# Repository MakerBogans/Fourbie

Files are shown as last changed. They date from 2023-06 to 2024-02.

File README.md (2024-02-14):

# Fourbie

## Important note
The following information is in regards to the differences between Fourbie v1 and Fourbie v2.
They are both AWD mods for voron 2.4 that use top moutned rails and VZ toolheads. However they are quite different in implementation.
They are labeled v1 and v2 as that is the order they are developed in. v1 is more flexible and compatible if you want to pick and choose which parts of the mod to use, see below. If starting from scratch I strongly recommend you go with v2. v1 is no longer in Active development, however they will continue to be distributed for those who may find them useful in some way.

These are two separate mods, both distributed from this repository in different sub-folders.
Links to the CAD can be found below. Documentation about the specific mods can be found in their specific folders README.MD

CAD can be found here:  https://drive.google.com/drive/u/0/folders/1L2iNjBxE2YqSRG2WW0IpDFqYx307Jbbb

Trident Mods exist in the mods folders

## V2
https://github.com/MakerBogans/Fourbie/tree/main/Fourbie%20v2
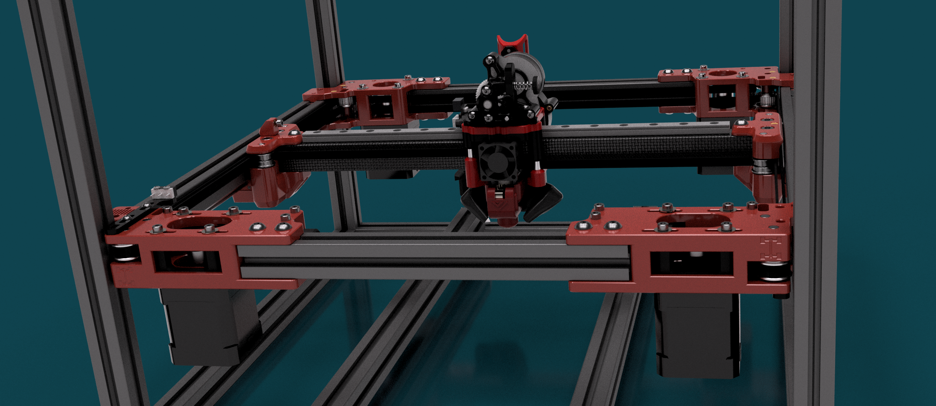
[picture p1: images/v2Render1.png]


## V1
https://github.com/MakerBogans/Fourbie/tree/main/Fourbie%20v1
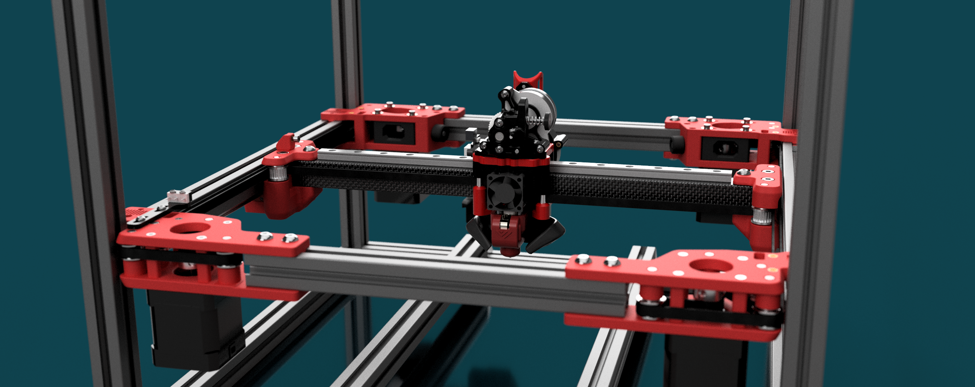
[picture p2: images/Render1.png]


V1 and v2 are very different. Here are some renders of the belt paths:

## v1
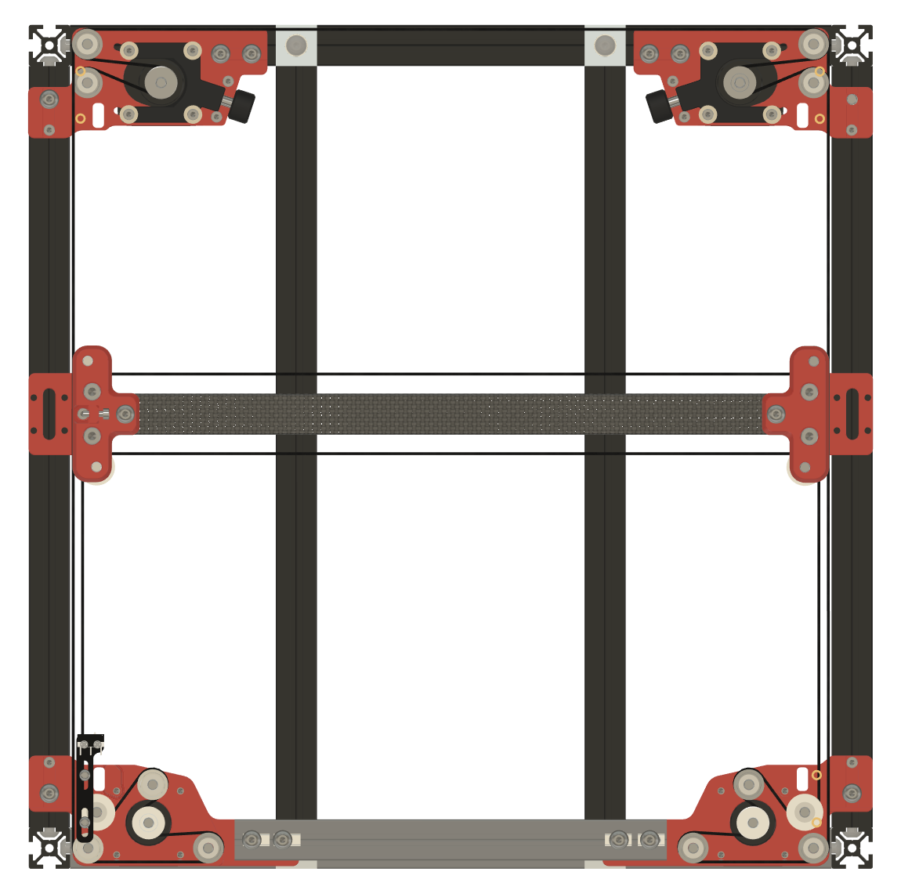
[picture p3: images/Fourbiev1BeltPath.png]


## v2
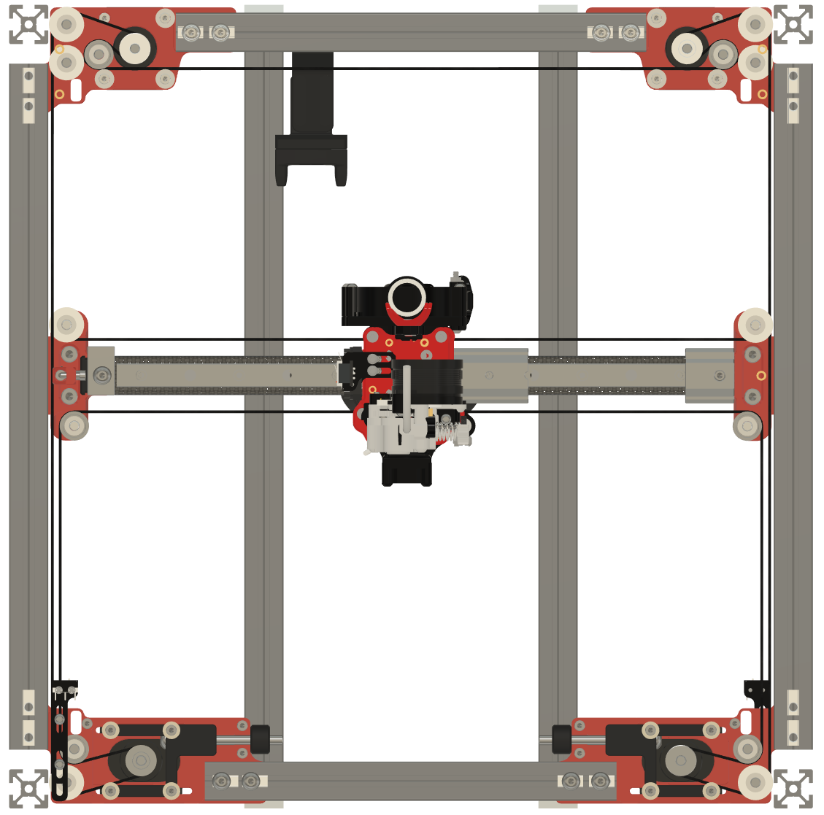
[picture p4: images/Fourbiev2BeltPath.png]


## Main differences:
   * Less idlers, simpler belt path. Less complexity means less failure points. 

   * ~15mm of tensioner travel

   * Tensioners at the front

   * Belts run in front of the rear extrusion. All belts and idlers can now be inspected from within the chamber to ensure they are running true.

   * Easy access to grub screws for syncing motors. 

   * A bit less loss of Y travel

   * Tow versions of AB joints, including one set that is much chonkier with an extra couple of mm of material in the AB drives. These resist twist far more than the standard thickness ones, or stock Voron AB.

   * Lots of minor fixes to alignment and geometry

   * No longer compatible with redoubt parts - v2 is an all in one system with front and rear AB and XY joints designed to be used together.

   * Currently only configured to support CF Tube for the X member. Extrusion or others could be added, not currently supported. 

It's still compatible with the VZ printhead, with the same belt spacing. Refer to the VZ-Prinhead-Printed repo for toolhead information.  
Overall it's a more robust and performant mod than v1. We will continue to distribute the files for v1 as the seprate mods and vasrious configurations this enables still have value - but if you are looking to do the whole system together - while this is a bigger change from stock I would strongly recommend v2 over v1. Any questions should be directed to @TheMrFish on discord, I will happily answer your queries. 

## Credit/Attribution
Credit goes to the Voron team for they great work creating the Voron 2.4 https://vorondesign.com/voron2.4
Annex Engineering that inspired some elements of the rear AB drives.  https://github.com/Annex-Engineering/Redoubt
Aive from the Makerbogans discord who's work on an AWD drive system for voron 2.4 defined the belt path for the front AB drives. 
The VZBot team for the VZ printhead - which made developing this mod much faster and also allows for the the use of many more toolhead configurations than we would have provided support for otherwise. https://github.com/VzBoT3D/Vz-Printhead-Printed
Thanks to Vez for giving permission to include the printhead in the CAD.

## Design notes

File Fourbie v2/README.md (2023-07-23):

# Fourbie v2



Fourbie v2 is an AWD mod for Voron 2.4 designed to increase the performance of the v2 and unlock more of the potential of this platform. It utilises a top mounted rail, VZ printhead style printhead and a more balanced belt path. 
While I will not make specific performance claims I can say that in testing, this goal has been met and this mod has led to significant accelleration, top speed and square corner velocity gains on the machines it has been tested on. 
Fourbie v2 is in Beta. 
No documentation is currently available for fourbie v2, so you will need to look right through the CAD for BOM and assembly. This will be remedied in time. See below for a list of changes from Fourbie v1 to v2. But note they are very different mods and should be considered as entirely distinct. They are v1 and v2 because that is the order they were developed. Note that other are taking efforts to mod fourbie v1 and v2 for Trident. I will include these in the repo as mods at the request of the developers. 
Google Drive link below has links to the CAD - they are too big to fit on github here. Please reach out to me TheMrFish on Discord if you have any questions.

https://drive.google.com/drive/u/0/folders/1L2iNjBxE2YqSRG2WW0IpDFqYx307Jbbb

## Options

### 4" lift
These parts are thicker versions of the front and rear AB drives which we have found to be SIGNIFICANTLY stiffer. Back to back testing of performance has not been tested. I suspect they will perform better and may become the standard. Note that you may need to add washers/use longer bolts for your z belt mounting to fit them - I have not specifically looked at the length of this bolt at the time of writing. 

## BOM:
We don't have a comprehensive BOM. I recommend you inspect the CAD to see what you need. But here is some useful info:

### X Gantry:
At the time of writing you will require a CF tube for the X beam. I designed to be compatible with the Unique Prints CF tubes. These have an M5 hole 7mm from the end. Several users have used generic CF tube off Aliexpress and drilled to specification with success. I am open to modifying this for an extrusion, CNC alu member or alternate CF tubes. Reach out to me on discord. No guarantees.

### Printhead
See the VZ-Printhead-Printed for details of what you will need to support the VZ printhead. There are some mods to the printhead in the STL's - no further documentation regarding these mods is provided at this time

### Other bits
You will definitely need:
* 2x extra motors for AB. Note that the older voron spec 0.9 degree steppers don't like high speeds, seem to be limited to under 350mm/s @ around 15k which will limit the potential of this machine. You may benefit from a 1.8 degree 2A motor or better.
* Steppers to support the extra motors
* 5mm shafts for the bearing stacks, and all appropriate shims
* 8x Toothed Idlers(including what you may have already) - narrow flanged versions like the ones Mellow sell are recommended. Depending on width, wide flanged ones may bind on the xy joints against the extrusion. In this case you are better off using bearing stacks and shims rather than toothed idlers. https://a.aliexpress.com/_mtE7JaI
* Additional belt - the belt path is SLIGHTLY longer - you will need more belts.
* 2x 55, 60 or 65mm M5 bolts for the tensioners
* The standoffs/spacers for the vz toolhead - again check vz bom.
* Some way of handling your wiring. We will provide mods for z chain mounts as some users are using these. I run an umbillical straight to the top, and a second umbillical to the top for the motors. Most of you will be running bottom mounted electronics, so mods for the chain will be provided asap. CANbus boards, if they can be made reliably would be a nice option for this toolhead. 
* A hotend of appropriate length to support the VZ toolhead. Mosquito/NF crazy with volcmosq or longer. Again see the VZ-Printhead-Printed repo for more information.
* you will need a front extrusion cut to length, see cad, add 50mm for a 300 and 100mm for a 350.
* Stronly recommend you use an MGN9 for the top rail. It weighs almost half as much and the extra stability from MGN 12 isn't needed like it is in the stock voron gantry. This is one of the main reasons I made this mod in the first place, and you should see significant performance gains from this. MGN12 is untested. 

## Important notes

### Syncing motors
All CoreXY AWD setups should have tensioning done:
* With the motors disabled and the grub screws for the pulleys on one of the motors on each belt loosened. 
* The grub screws on that pulley should not engage with the D cut, rather they should engage on the round. 
* Once desired tension has been found and motor screws tightened you should energise your motors before tightening the grub screws.
If you notice a clunk sound when you disable your motors at any point you will need to repeat this process. This is probably best done with the printer at working temperature as belts change lenght over time. See Vez's video on syncing motors on AWD VZ Bot printers for additional info on this. 

### Sensorless homing
This can and has worked with this setup. I will share my thoughts on this, note that I am currently using endstops instead.
I've had issues with reliability and tuning sensorless homing on AWD.
My working theory is as follows:
In a 2wd setup the load from bashing in to the gantry acts on both sides of the belt going in to the motor. 
In AWD there is another whole motor on the belt, taking up some of the load, and the belt run between the two motors is likely not seeing as much of that force as it homes. 
That and if the pulleys on both motors are not perfectly concentric then there is going to be like a wave of loading and unloading tension as it goes through the range of movement. If the motors are not sync'ed then this effect is even worse. 
It can work, and has worked. But I gave up on it and went to microswitches as I was finding it a waste of time. Took less time to wire up some microswitches that I had spent troubleshooting it.

### Concentric pulleys
Make sure you have good pulleys. Having two pulleys with offset concentricity on the same belt WILL cause additional load on your motors and lead to performance issues. Any bent motor shafts will also cause you problems. Quality motor pulleys for XY are recommended.

-- @TheMrFish

## Credit/Attribution
Some screenshots of some sketches of parts of potential belt paths that Jakoob874 on discord served as inspiration for Fourbie v2 and it would not exist without that. 
Credit goes to the Voron team for they great work creating the Voron 2.4 https://vorondesign.com/voron2.4
Annex Engineering that inspired some elements of the rear AB drives.  https://github.com/Annex-Engineering/Redoubt
Aive from the Makerbogans discord who's work on an AWD drive system for voron 2.4 defined the belt path for the front AB drives. 
The VZBot team for the VZ printhead - which made developing this mod much faster and also allows for the the use of many more toolhead configurations than we would have provided support for otherwise. https://github.com/VzBoT3D/Vz-Printhead-Printed
Thanks to Vez for giving permission to include the printhead in the CAD.

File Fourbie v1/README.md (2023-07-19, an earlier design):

# Fourbie v1


Fourbie is a collection of mods aimed at increasing the performance of the Voron 2.4. 
In short it's an AWD system with a VZBot style toolhead. The X rail mounts on top of the X member and the toolhead is balanced over the top. Belts terminate on the front on one end and the rear on the other. This leads to a more balanced gantry than the stock voron allowing for increased performance. A front extrusion is added to support the front AB drives. There is support for CF tubes and extrusions. It also supports the use of a single MGN9 or MGN12.

The primary components of the MOD are 
* Front AB drives for AWD Support
* Rear AB drives with integrated Tensioners
* XY Joints

CAD can be found here: 

   https://drive.google.com/file/d/1AhVO8JxvDxypqgWyNXzLK3HZzntU7isS/view?usp=sharing
   https://drive.google.com/file/d/1FDfTh_o8sUtzyHR29BRvmarWRINtGYFZ/view?usp=drive_link
   
STL's are in this repository

These are all designed to be used together, however they could be used in a number of other configurations
Possible configurations include:

    * AWD with all of the mods and VZ printhead style toolheads.
    
    * AWD with using the front and rear AB drives from this mod, Redoubt XY Joints and Voron style toolheads. 
    
    * 2WD using the XY Joints and rear AB from this mod, Redoubt front idlers and VZ Printhead style toolheads.

The standard configuration is all of the above mods together. This is what is tested. All other potential configurations are untested. 
Note that this is an advanced mod. There is no build documentation. Bom will not be comprehensive. It is expected that you will inspect the CAD and do the work to figure out what you need to install it. 

Due to the number of idlers, you need to build to spec and take your time to make sure everything is properly built and aligned, front to back. Failure to do this will lead to your fourbie eating all of your belts. Nom. Also before printing make sure that you have properly tuned your filament and that it is producing dimensionally accurate parts. This MOD has been designed with very tight tolerances and improper calibration will lead to problems. 

## XY Joints
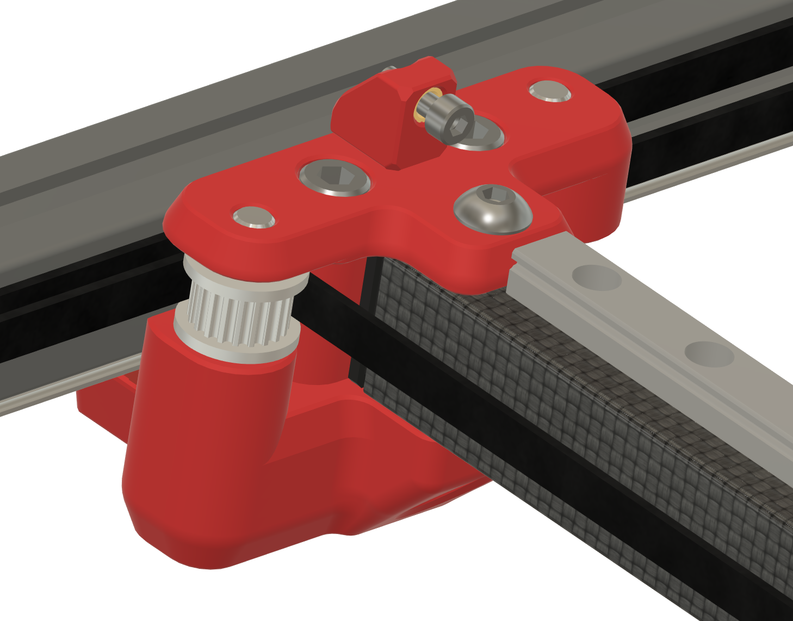
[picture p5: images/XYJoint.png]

Two versions of the XY joints are included in the mod, one for CF tubes and one for extrusions.
From our testing a CF tube provides better performance.
Either version supports MGN12 or MGN9. The more balanced gantry allows for the use of MGN9 as having the toolhead balanced over the top of the rail rather than hanging off the front means that a lighter duty rail can be used without degrading stability. In our testing the weight savings by going to MGN9 leads to better performance.
The front idler positioning is the same as Redoubt meaning this is compatible with Redoubt front idlers with either the rear AB drives from this mod or the Redoubt motor mounts. 
The XY joints are designed to be used with pins rather than bolts(Voron default) or shoulder screws(Redoubt default)

## Front AB drives. 
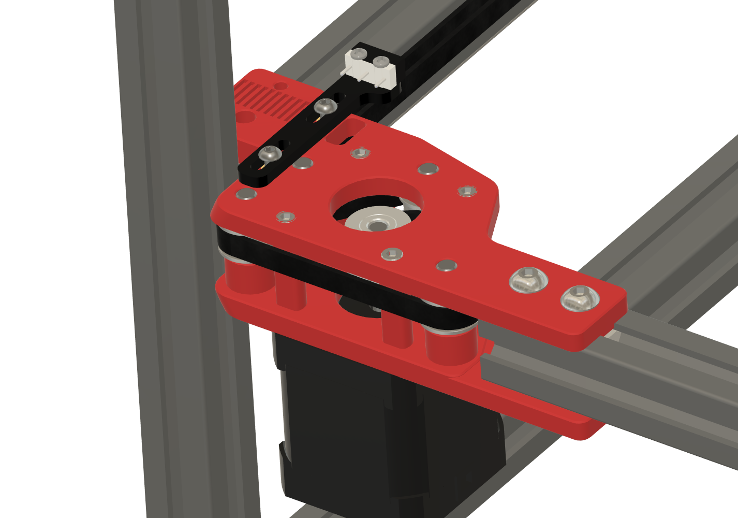
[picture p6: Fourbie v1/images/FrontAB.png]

There are two versions of the Front AB drives. 

    * With Extrusion
    
    * Without extrusion

Front AB drives without extrusion are untested and not recommended. The addition of a front extrusion stabilises the front AB drives. The addition of motors on the front of the gantry could lead to the fron AB drives twisting and could cause problems with your belts. Extrusion length is 210mm/260mm/310mm for v2.4 250/300/350.
All idler and pulley stacks use pins rather than bolts. As per design all smooth idlers are designed to use bearings, and toothed idlers use toothed idlers. There is support in the CAD for Gates genuine and non-genuine idlers. 

The return belts for the AB drives use redoubt belt spacing and therefor are compatible with redoubt XY joints. 

## Rear AB drives
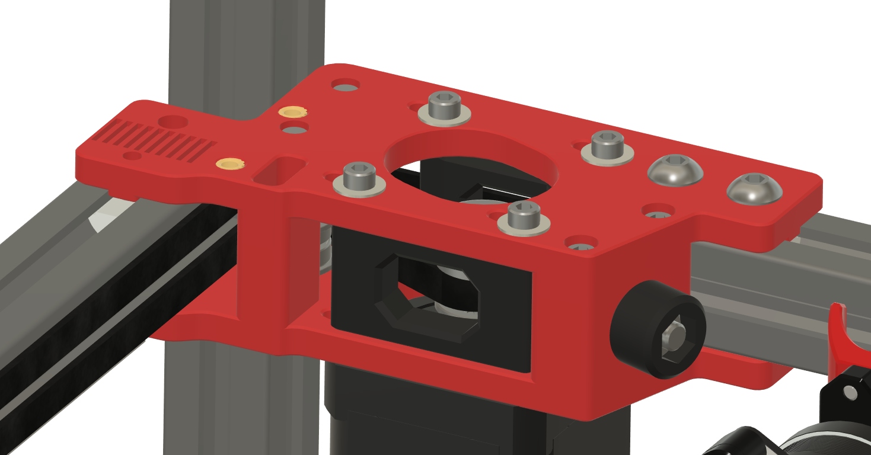
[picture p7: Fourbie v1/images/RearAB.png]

Rear AB drives use integrated tensioners using an M5 bolt. Design was originally based on the Redoubt idlers, but then heavily modified to allow for visibility of the pulleys so you can confirm that your belts are running true.
Note that as with the XY joints and Front AB drives these are designed for use with pins rather than bolts or shoulder screws for the idler stacks. 
Rear AB drives allow for about 6.5mm of tensioning travel. This is enough, though you will want to put a little bit of tension on your belts when installing them
## Recommended configuration

* MGN9 for X rail.
* CF Tube for X rail
* Front AB drives with extrusion

An NF Crazy or Mosquito is recommended to minimise loss of Y. With an NF crazy there is no loss of X and about 25mm loss on Y. Given that most people generally  do not print in the outer 1cm of the bed on Voron this is very little real world loss of build volume. 
We are looking at options for BerdAir to reduce loss of build volume down to the minimum. 

## Tips
It's easiest to run the belts without the tops on the front and rear AB drives. 

## BOM

.... we might put something here. 

## Credit/Attribution
Credit goes to the Voron team for they great work creating the Voron 2.4 https://vorondesign.com/voron2.4
Annex Engineering that inspired some elements of the rear AB drives.  https://github.com/Annex-Engineering/Redoubt
Aive from the Makerbogans discord who's work on an AWD drive system for voron 2.4 defined the belt path for the front AB drives. 
The VZBot team for the VZ printhead - which made developing this mod much faster and also allows for the the use of many more toolhead configurations than we would have provided support for otherwise. https://github.com/VzBoT3D/Vz-Printhead-Printed
Thanks to Vez for giving permission to include the printhead in the CAD.

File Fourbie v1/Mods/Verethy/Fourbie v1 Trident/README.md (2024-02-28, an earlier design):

# Fourbie v1

Fourbie is a collection of mods aimed at increasing the performance of the Voron 2.4/Trident. 
In short it's an AWD system with a VZBot style toolhead. The X rail mounts on top of the X member and the toolhead is balanced over the top. Belts terminate on the front on one end and the rear on the other. This leads to a more balanced gantry than the stock voron allowing for increased performance. A front extrusion is added to support the front AB drives. There is support for CF tubes and extrusions. It also supports the use of a single MGN9 or MGN12.

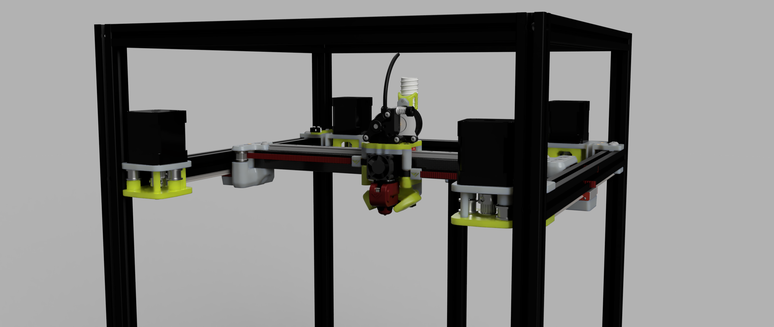
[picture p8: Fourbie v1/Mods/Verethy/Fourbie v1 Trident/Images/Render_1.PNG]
Trident1


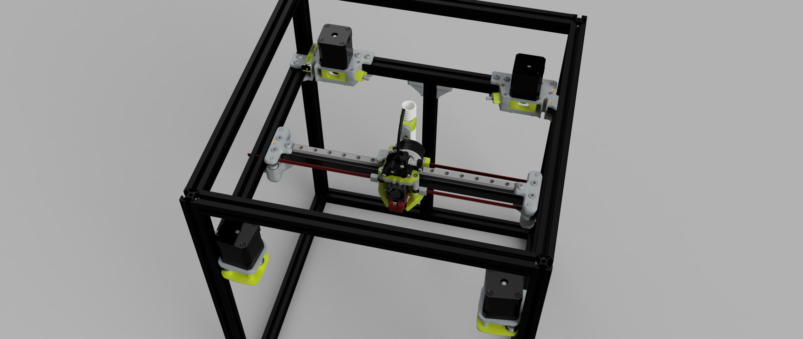
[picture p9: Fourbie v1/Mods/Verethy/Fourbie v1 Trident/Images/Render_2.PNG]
Trident2


The primary components of the MOD are 
* Front AB drives for AWD Support
* Rear AB drives with integrated Tensioners
* XY Joints

STL's are in this repository

These are all designed to be used together, however they could be used in a number of other configurations
Possible configurations include:

    * AWD with all of the mods and VZ printhead style toolheads.
    
    * AWD with using the front and rear AB drives from this mod, Redoubt XY Joints and Voron style toolheads. 
    
    * 2WD using the XY Joints and rear AB from this mod, Redoubt front idlers and VZ Printhead style toolheads.

The standard configuration is all of the above mods together. This is what is tested. All other potential configurations are untested. 
Note that this is an advanced mod. There is no build documentation. Bom will not be comprehensive. It is expected that you will inspect the CAD and do the work to figure out what you need to install it. 

Due to the number of idlers, you need to build to spec and take your time to make sure everything is properly built and aligned, front to back. Failure to do this will lead to your fourbie eating all of your belts. Nom. Also before printing make sure that you have properly tuned your filament and that it is producing dimensionally accurate parts. This MOD has been designed with very tight tolerances and improper calibration will lead to problems. 

## Recommended configuration

* MGN9 for X rail.
* CF Tube for X rail
* Front AB drives with extrusion

An NF Crazy or Mosquito is recommended to minimise loss of Y. With an NF crazy there is no loss of X and about 25mm loss on Y. Given that most people generally  do not print in the outer 1cm of the bed on Voron this is very little real world loss of build volume. 
We are looking at options for BerdAir to reduce loss of build volume down to the minimum. 

## BOM

For the front drive mounts you need:
2x 2GT toothed idlers (3mm bore)
4x 2GT smooth idlers (3mm bore)
12x M3x5x0.5mm shims

## Credit/Attribution
Credit goes to the Voron team for they great work creating the Voron 2.4 https://vorondesign.com/voron2.4
Annex Engineering that inspired some elements of the rear AB drives.  https://github.com/Annex-Engineering/Redoubt
Aive from the Makerbogans discord who's work on an AWD drive system for voron 2.4 defined the belt path for the front AB drives. 
The VZBot team for the VZ printhead - which made developing this mod much faster and also allows for the the use of many more toolhead configurations than we would have provided support for otherwise. https://github.com/VzBoT3D/Vz-Printhead-Printed
Thanks to Vez for giving permission to include the printhead in the CAD.

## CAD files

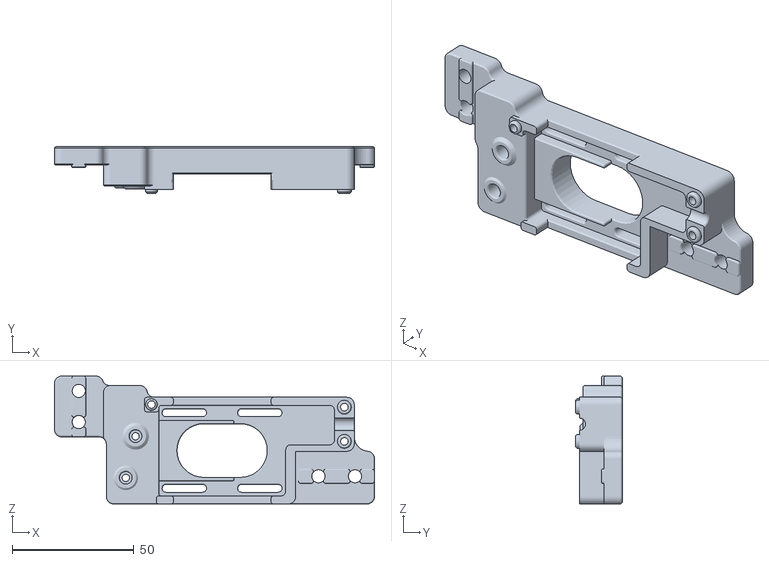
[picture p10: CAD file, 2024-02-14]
Fourbie v2/Mods/Killajoedotcom/AB Drives for Trident/Front AB Drives/4 Inch Lift/Thicker Front Left_Fourbie v2_Bottom.stl
131.4 x 19.1 x 52.5

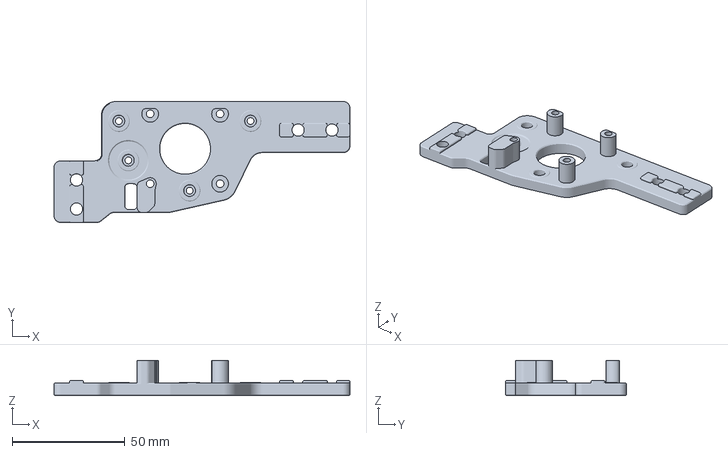
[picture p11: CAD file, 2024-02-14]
Fourbie v2/Mods/Killajoedotcom/AB Drives for Trident/Front AB Drives/Front AB - Right - Bottom.3mf
131.3 x 53.7 x 15.6 mm

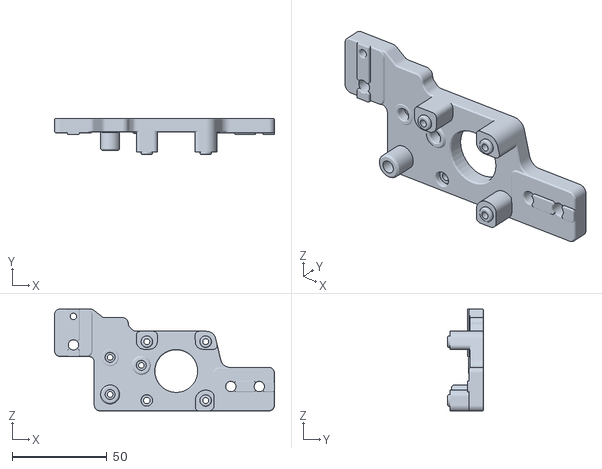
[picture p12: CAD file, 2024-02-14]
Fourbie v2/Mods/Killajoedotcom/AB Drives for Trident/Rear AB Drives/4 Inch Lift/Thicker Rear Right_Fourbie v2_Bottom.stl
115.9 x 19.1 x 53.7

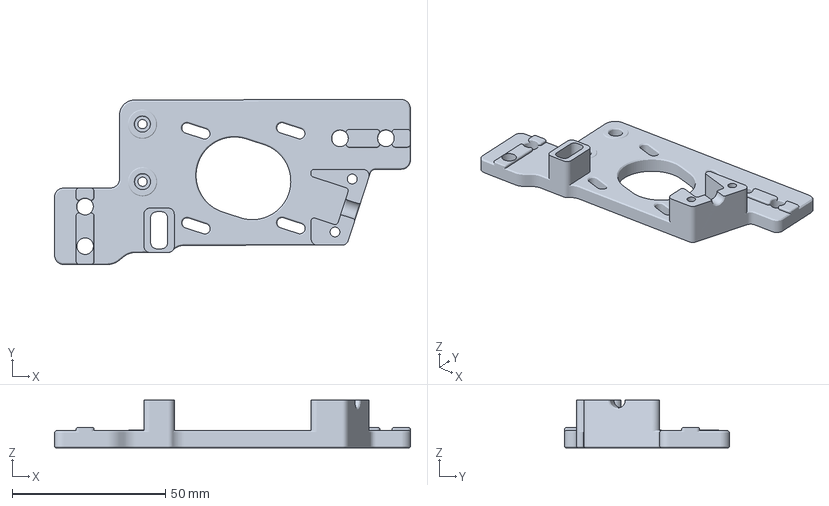
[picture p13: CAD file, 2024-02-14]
Fourbie v2/Mods/Killajoedotcom/AB Drives for Trident/Rear AB Drives/Rear AB - Left - Bottom.3mf
116.2 x 53.9 x 15.6 mm

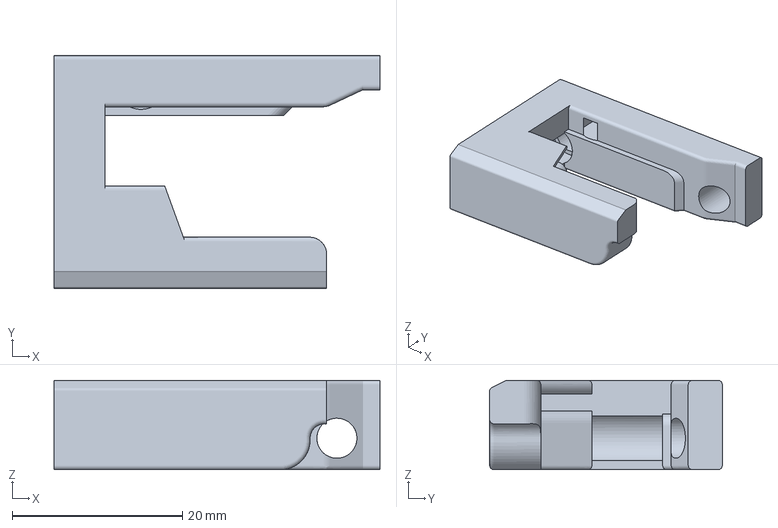
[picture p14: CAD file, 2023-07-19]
Fourbie v2/Mods/Verethy/Eureaka Probe Dock/Probe_Dock.3mf
38.3 x 27.3 x 10.5 mm

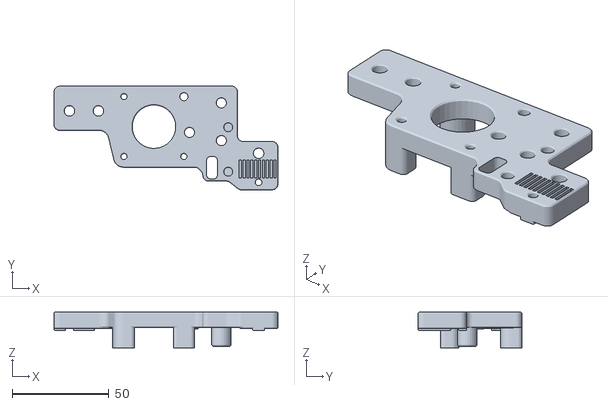
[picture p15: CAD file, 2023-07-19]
Fourbie v2/STL/AB/4 Inch Lift/v26 - 4 Inch Lift - Rear Right - Top.stl
115.9 x 53.7 x 18.6

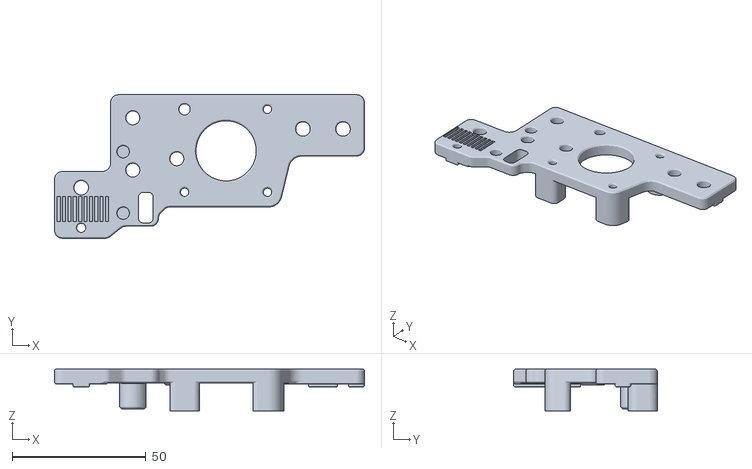
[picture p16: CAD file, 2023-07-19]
Fourbie v2/STL/AB/v26 - Rear Left - Top.stl
115.9 x 53.7 x 15.6

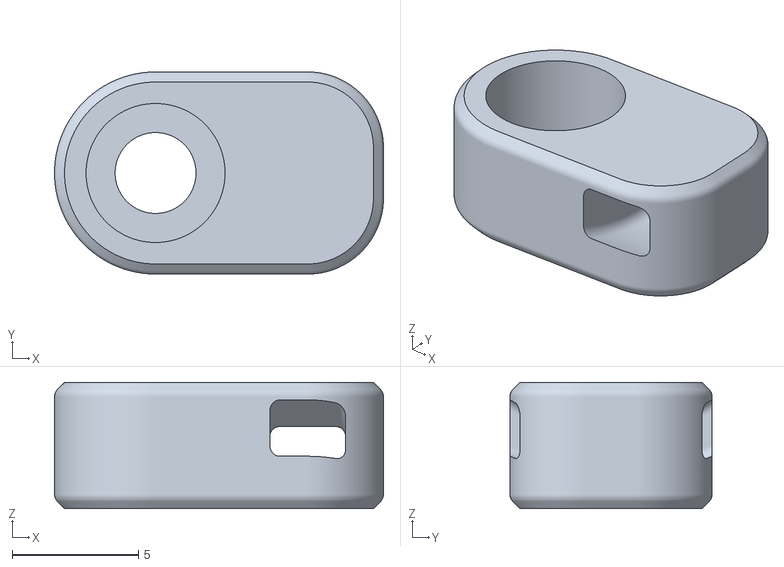
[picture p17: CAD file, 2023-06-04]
Fourbie v2/STL/Cable Tie Mounts/Cable Tie Mount - Flat.stl
13.0 x 8.00 x 5.00

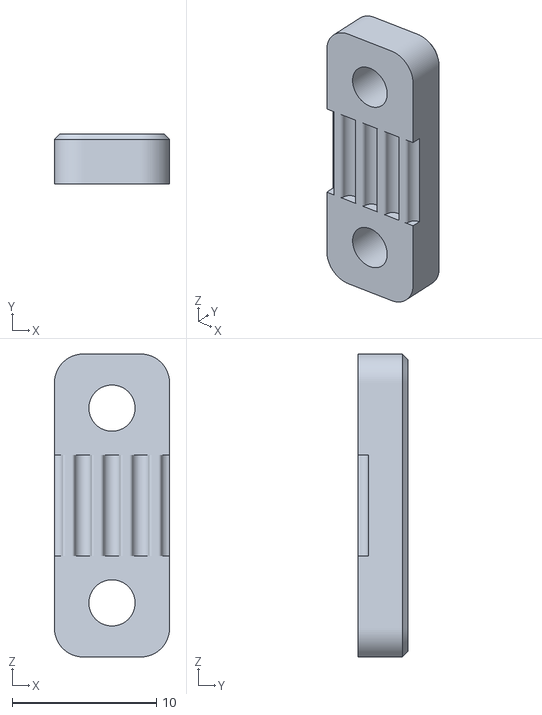
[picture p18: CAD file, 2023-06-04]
Fourbie v2/STL/Toolhead/Alternative front belt clamps/Toothed Belt Clamp - Front - x2 -Print Solid!.stl
7.98 x 3.50 x 21.0

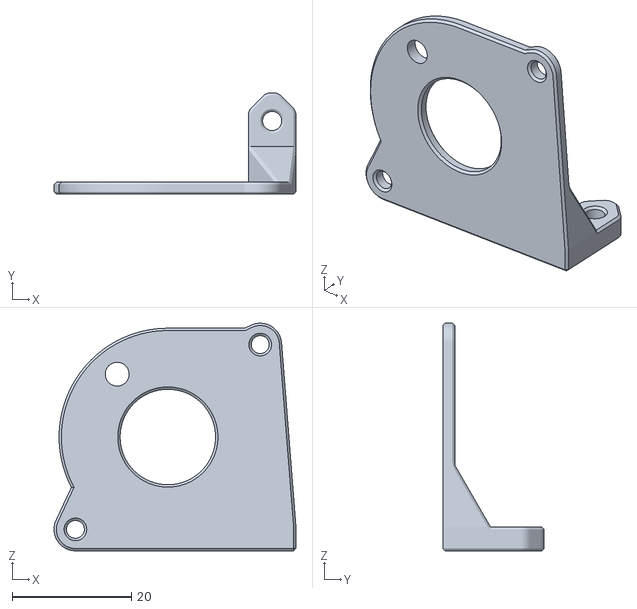
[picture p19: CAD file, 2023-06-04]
Fourbie v2/STL/Toolhead/VZBot Toolhead Mods/LGX Lite Support Midplate Plate for stock VZBot Toolhead.stl
40.6 x 17.0 x 38.2

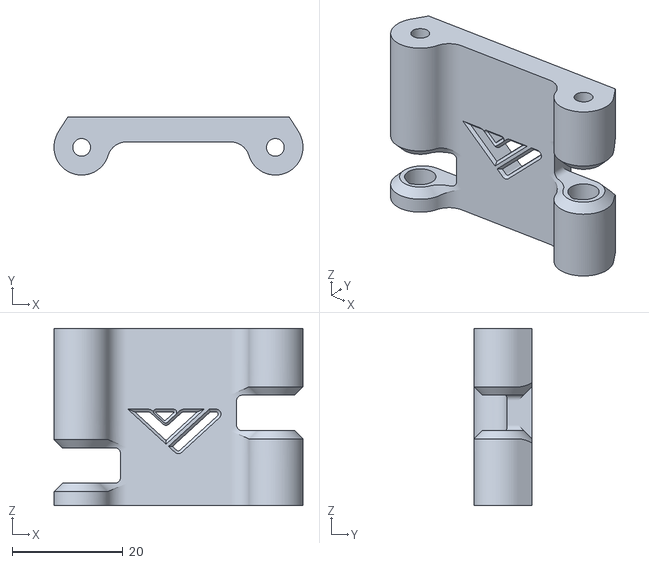
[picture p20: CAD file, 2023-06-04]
Fourbie v2/STL/Toolhead/VZBot Toolhead Mods/MGN9/Backplate with no mast.stl
45.0 x 10.5 x 32.0

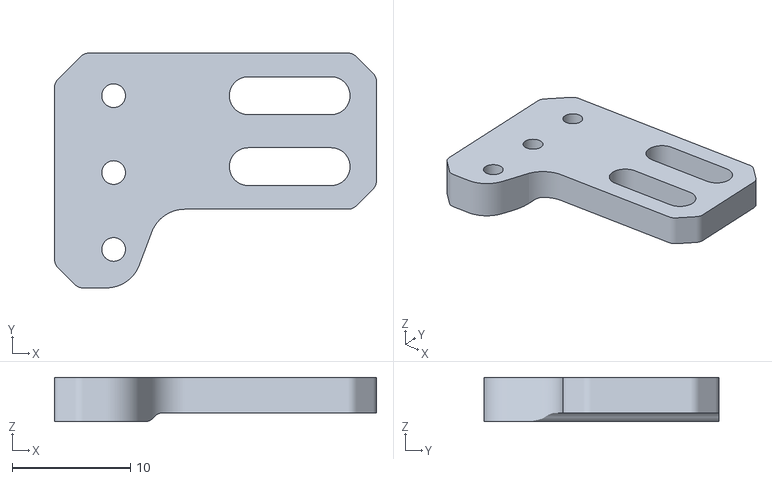
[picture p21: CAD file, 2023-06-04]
Fourbie v2/STL/Toolhead/X Endstop Switch Mount.stl
27.2 x 19.8 x 3.75

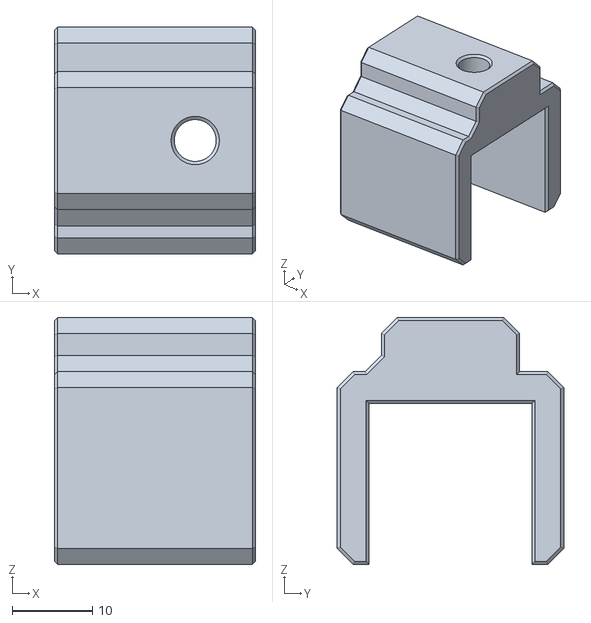
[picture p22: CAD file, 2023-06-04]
Fourbie v2/STL/Tools/CF Tube Drill Guide MGN9 Rail End Retainer x2.stl
25.0 x 28.2 x 30.7

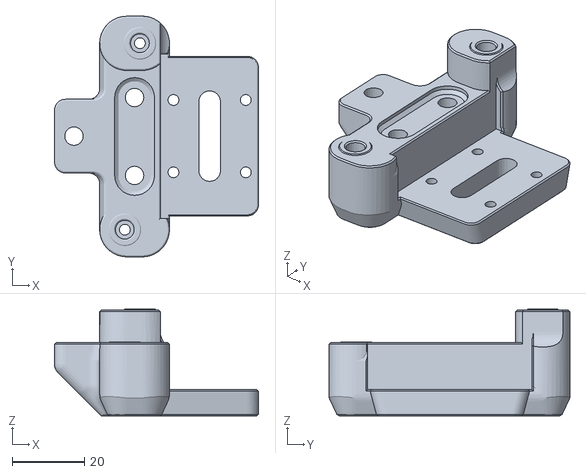
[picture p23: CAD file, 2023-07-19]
Fourbie v2/STL/XY Joints/MGN12/MGN12 XY Joints - Right - Bottom.stl
56.4 x 66.5 x 29.5

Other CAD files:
Fourbie v2/STL/XY Joints/v27 - Left XY Joint - Bottom.stl
Fourbie v2/Mods/Killajoedotcom/AB Drives for Trident/Front AB Drives/4 Inch Lift/Thicker Front Left_Fourbie v2_Tensioner Frame_x2.stl
Fourbie v2/Mods/Killajoedotcom/AB Drives for Trident/Front AB Drives/Front AB - Left - Top.3mf
Fourbie v2/Mods/Killajoedotcom/AB Drives for Trident/Rear AB Drives/4 Inch Lift/Thicker Rear Right_Fourbie v2_Top.stl
Fourbie v1/Mods/Verethy/Fourbie v1 Trident/STL/Front AB/Bottom Left.3mf
Fourbie v1/Mods/Verethy/Fourbie v1 Trident/STL/Front AB/Bottom Right.3mf
Fourbie v1/Mods/Verethy/Fourbie v1 Trident/STL/Front AB/Top Left.3mf
Fourbie v1/Mods/Verethy/Fourbie v1 Trident/STL/Front AB/Top Right.3mf
Fourbie v1/Mods/Verethy/Fourbie v1 Trident/STL/Front AB/[a]_a_drive_front_lower.3mf
Fourbie v1/Mods/Verethy/Fourbie v1 Trident/STL/Front AB/[a]_b_drive_front_lower.3mf
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

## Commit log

2023-07-19 Fourbie v2 multistage commit(because timeout) 1
    [Cable Tie Mount - Flat top wide base.stl, Cable Tie Mount - Flat.stl, Cable Tie Mount - Wider Base.stl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]
2023-07-19 multi stage commit(because timeout) 2
    [Backplate with no mast.stl, CF Tube Drill Guide MGN9 Rail End Retainer x2.stl, CF Tube Drill Guide MGN9 Rail Retainer.stl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]
2023-07-19 multistage commit 3
    [Front Left - Bottom - v22 .stl, v22 4 Inch Lift - Front AB - Left - Bottom.stl, v22 4 Inch Lift - Front AB - Left - Top.stl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]
2023-07-19 multistage commit 4
    [Backplate with no mast.stl, CF Tube Drill Guide MGN9 Rail End Retainer x2.stl, CF Tube Drill Guide MGN9 Rail Retainer.stl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]
2023-07-19 removing old
    [Front Left - Bottom - v22 .stl, Front Left - Tensioner Frame.stl, Front Left - Top - v22.stl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]
2023-07-19 removing archived
    [v22 4 Inch Lift - Front AB - Left - Bottom.stl, v22 4 Inch Lift - Front AB - Left - Top.stl, v22 4 Inch Lift - Front AB - Right - Bottom.stl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]
2023-07-19 added mod for top mounted y rails
    [Upsidedown_XY_v3.f3d]
2023-08-23 Adding Trident V1
    [Bottom Left.3mf, Bottom Right.3mf, Top Left.3mf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]
2024-02-14 Added Fourbie Trident mods KillaJoe and Verethy and re-organised mods
    [Bottom Left.3mf, Bottom Right.3mf, Front AB - Left - Bottom.3mf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]
2024-02-28 Fourbie Trident V1 Update
    Fourbie Trident V1 Update
    [Bottom Left.3mf, Bottom Right.3mf, Left XY Joint CF Tube Lower.3mf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]
